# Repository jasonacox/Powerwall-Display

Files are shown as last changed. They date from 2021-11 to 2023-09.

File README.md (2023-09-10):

# Powerwall-Display
Tesla Powerwall display based on 7-segment TM1637 displays and ESP8266 to show current solar generation, powerwall (power and percentage), grid and load power usage. 

Powerwall-Display-Video (https://www.youtube.com/watch?v=8YzZw6ldIqQ "Play Video")

* Display1 (4-digit white/yellow): Solar Power Generated
* Display2 (6-digit red): Rotates thought the following Power metrics:
    * (H)ouse Load
    * (E)lectric Grid + direction animation
    * (P)owerwall Battery + direction animation
* Display3 (4-digit green): Powerwall Battery (% Full) + animation for charge/discharge

The display will show values in watts (W) for 1-9999W values and kilowatts (kW) for 10.0kW and above.
     
## 3D Printed Model
The 3D printed case houses the ESP8266 WeMos controller, two 4-digit displays and one 6-digit display.  The model has a cutout TESLA logo that can be backlit.

* Thingiverse - [Link](https://www.thingiverse.com/thing:5113169)
* Local STL - [Link](TeslaSolarDisplay.stl)
* Tinkercad Original - [Link](https://www.tinkercad.com/things/3FTXlFyVO4z-tesla-solar-display)

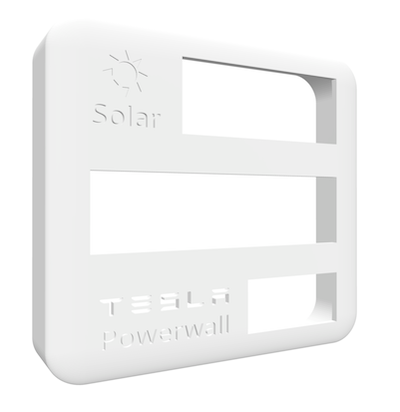
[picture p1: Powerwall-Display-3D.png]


## Electronics
The following components were used to build this kit:
* ESP8266 WeMos D1 Mini Controller - [Amazon](https://www.amazon.com/dp/B081PX9YFV/ref=cm_sw_em_r_mt_dp_48GWNB0ZD5XM511K98T9) | [AliExpress](https://www.aliexpress.com/item/1005001636509632.html?spm=a2g0s.9042311.0.0.21a34c4dPgfOzp)
* TM1637 0.56" 4-Digit LED Segment Display (White/Yellow) - [Amazon](https://www.amazon.com/dp/B07MCGDST2/ref=cm_sw_em_r_mt_dp_YD20SFT79CEE5465E9R0?_encoding=UTF8&psc=1) 
* TM1637 0.36" 4-Digit LED Segment Display (Green) - [Amazon](https://www.amazon.com/dp/B01DKISMXK/ref=cm_sw_em_r_mt_dp_17NDHA13Q8GRYH0W5KTG?_encoding=UTF8&psc=1)
* TM1637 0.56" 6-Digit LED Segment Display (Red) - [Amazon](https://www.amazon.com/dp/B08G1RYYTQ/ref=cm_sw_em_r_mt_dp_FHDSB6FT03TFHVS02QKB) | [AliExpress](https://www.aliexpress.com/item/1005002060120661.html?spm=a2g0s.9042311.0.0.21a34c4dPgfOzp)
* Optional - Green LEDs for Logo Backlight

## Powerwall Proxy
The display uses the [pyPowerwall proxy](https://github.com/jasonacox/pypowerwall/tree/main/proxy#pypowerwall-proxy-server) to connect with the Powerwall API. You you will need to install this on a local system (Raspberry Pi, Linux or Windows system) that is always running so that the display can pull the latest data. The proxy can be installed as a docker container.  Be sure to update the password, email, Powerwall host IP address and Timezone.

Proxy Install Instructions using Docker:

```bash
docker run \
    -d \
    -p 8675:8675 \
    -e PW_PASSWORD='your-powerwall-password' \
    -e PW_EMAIL='your-powerwall-email' \
    -e PW_HOST='your-powerwall-ip-address' \
    -e PW_TIMEZONE='America/Los_Angeles' \
    -e PW_CACHE_EXPIRE='20' \
    --name pypowerwall \
    --restart unless-stopped \
    jasonacox/pypowerwall
```

## Arduino Code
The code uses the [TM1637TinyDisplay](https://github.com/jasonacox/TM1637TinyDisplay) Arduino library to drive the 7-segment 4-digit and 6-digit displays (see installation [instructions here](https://github.com/jasonacox/TM1637TinyDisplay#installation)).

1. Use the Arudino sketch located [here](Powerwall-Display/Powerwall-Display.ino).

2. Update the Configuration Section for your Setup in the sketch:

```c++
// Configuration Settings           
#define FILTER 50               // Zero out power values less than this
#define PROXYHOST "10.0.x.x"    // Address of Proxy Server
#define PROXYPORT 8675          // Port of Proxy Server (default=8675)

// Wifi Configuration 
const char* WIFI_SSID = "WIFI_SSID";
const char* WIFI_PWD  = "WIFI_PASSWORD";

// Display GPIO Pins (Clock and Data)
#define CLK1 5    // Display 1 - 4-digit for SOLAR power display (Yellow)
#define DIO1 4
#define CLK2 14   // Display 2 - 6-digit for POWER display for Grid, Home and Powerwall (Red)
#define DIO2 12
#define CLK3 13   // Display 3 - 4-digit for BATTERY percentage (Green)
#define DIO3 16
#define TESLA 0   // Optional Tesla Logo LED
```

## Schematic

The cirucit is fairly simple. As noted above in the code, the ESP8266 module will need to drive the CLK (clock) and DIO (data) input on three different display modules, one 6-digit modules and two 4-digit modules. There is an optional output for the Logo LED.

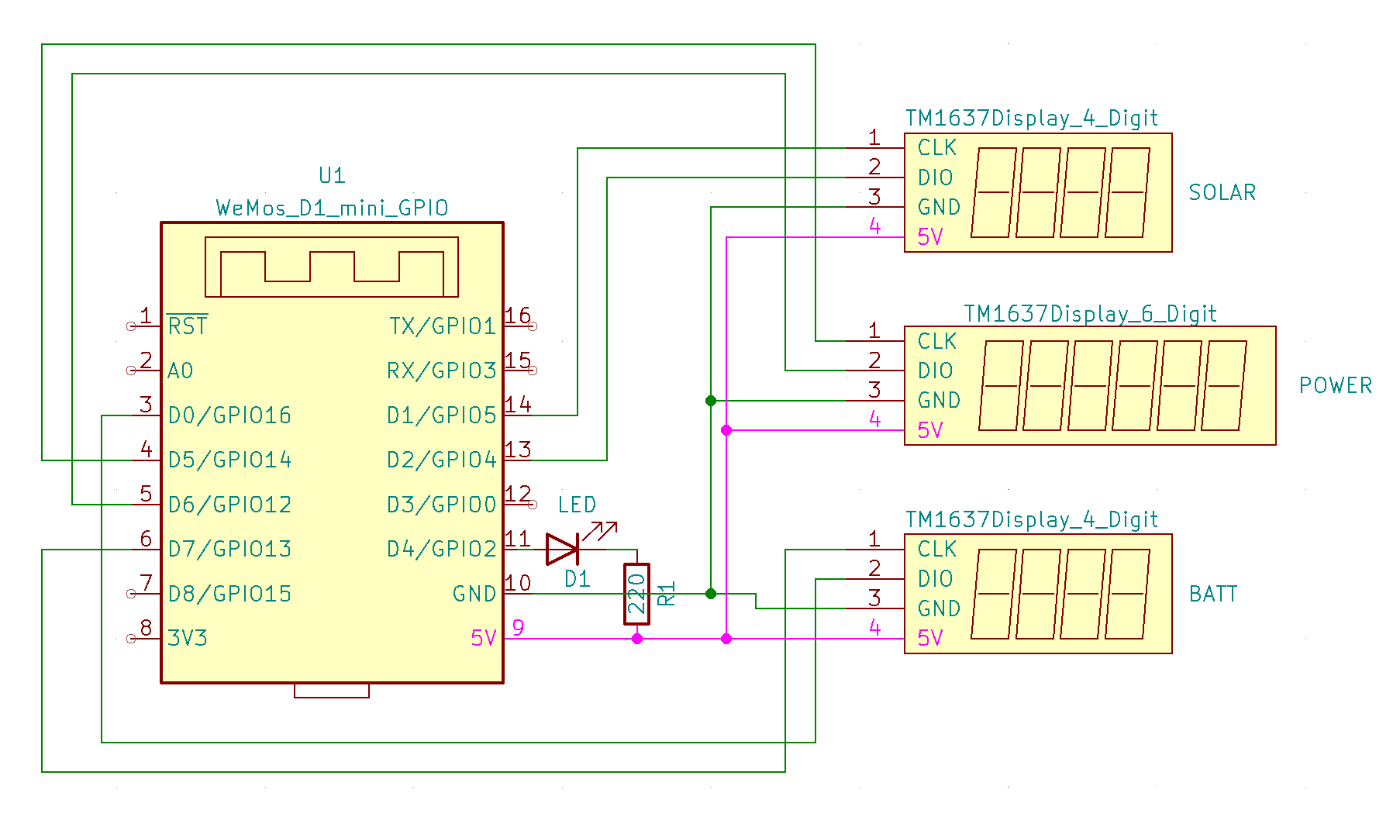
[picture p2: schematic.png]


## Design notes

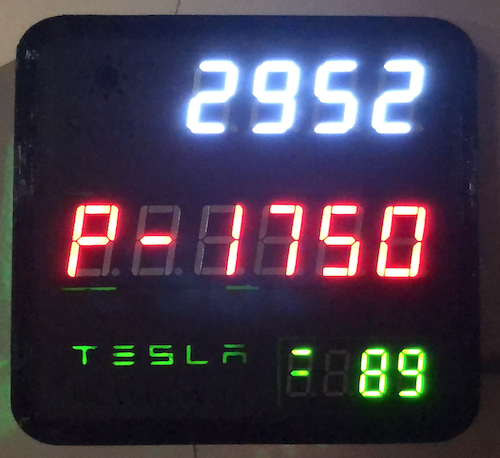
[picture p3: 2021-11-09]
Powerwall-Display.png

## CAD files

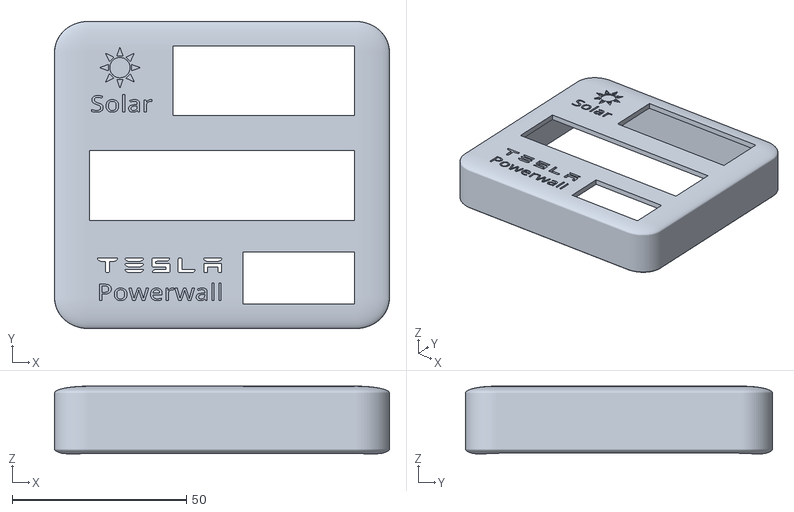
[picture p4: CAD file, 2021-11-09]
TeslaSolarDisplay.stl
96.0 x 88.0 x 19.4

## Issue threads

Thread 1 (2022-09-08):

ESP8266 to Powerwall

LucioB81, 2022-09-08:
Forst of all nice job, your work was very helpful!
One thing I can't seem to wrap my head around. Would it be possible to bypass the pypowerwall module and make the esp talk with the powerwall directly? I am obviously missing something but I cannot find what it is.

Thanks!
Lucio

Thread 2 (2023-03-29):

Issues communicating with the ESP8266

aparticka, 2023-03-29:
I find myself continually looking at the Tesla app to optimize usage (waiting to do laundry until the battery is nearing 100%, etc.). I figured something like this project would be possible and was happily surprised to find it, so thanks for all of the work that you've already done. I have the pypowerwall project running on a Raspberry Pi that I was using as a pihole already and that all works great, I can hit the /csv endpoint from my network and see the raw values. I ordered some of the parts you used - the ESP8266 modules and the 5-pack of different colored TM1637 displays. I have some Arduino experience, just playing around with a Mega 2560, but this particular ESP8266 is giving me issues (~90% of the time can't upload anything to it because it somehow can't connect to it). I was wondering if you also ran into any similar issues, and if so, how you fixed them. Thanks for reading if you made it this far, and thanks again for the well-documented project.

jasonacox, 2023-03-30:
Hi @aparticka - thanks for the kind words and encouragement!

Yes, I had issues with programming the ESP8266 from my MacBook and the Arduino IDE.  I needed to install the SiLabs [serial driver for the chip](https://www.silabs.com/products/development-tools/software/usb-to-uart-bridge-vcp-drivers) ([direct link](https://www.silabs.com/Support%20Documents/Software/Mac_OSX_VCP_Driver.zip)) - see https://github.com/nodemcu/nodemcu-devkit/wiki/Getting-Started-on-OSX .  You also need to install the Arduino board manager for ESP8266: http://arduino.esp8266.com/stable/package_esp8266com_index.json - this is done in the Arduino preferences settings:

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

Let me know if any of this helps. :)

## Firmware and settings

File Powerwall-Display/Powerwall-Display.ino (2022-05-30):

/*
  Powerwall-Display
  ESP8266 with Three TM1637 7-Segment Displays - STATIC WIFI SETTINGS
  https://github.com/jasonacox/Powerwall-Display

  Tesla Powerwall display based on 7-segment displays and ESP8266 to show 
  current solar generation, powerwall (power and percentage), grid and 
  load power usage.
  
  Description
     Three displays are set up to display metrics from Powerwall:
       Display1 (4-digit): Solar Power Generated (W)
       Display2 (6-digit): Rotates display of the following Power metrics:
                             (H)ouse Load (W)
                             (E)lectric Grid (W) + direction animation
                             (P)owerwall Battery (W) + direction animation
       Display3 (4-digit): Powerwall Battery (% Full) + animation

     Displays in W unit for 1-9999W values and kW for 10.0kW and above.

  This sketch requires pyPowerwall proxy - http://<proxy-address>:8675/csv

     Proxy Install Instructions:
          docker run \
              -d \
              -p 8675:8675 \
              -e PW_PASSWORD='your-powerwall-password' \
              -e PW_EMAIL='your-powerwall-email' \
              -e PW_HOST='your-powerwall-ip-address' \
              -e PW_TIMEZONE='America/Los_Angeles' \
              -e PW_DEBUG='yes' \
              -e PW_CACHE_EXPIRE='20' \
              --name pypowerwall \
              --restart unless-stopped \
              jasonacox/pypowerwall

  Author: Jason A. Cox - @jasonacox
  Date: 1 November 2021
*/

#define VERSION 1.00
#define SENSORID 101 

// Configuration Settings           
#define FILTER 50               // Zero out power values less than this
#define PROXYHOST "10.0.x.x"    // Address of Proxy Server
#define PROXYPORT 8675          // Port of Proxy Server (default=8675)

// Wifi Configuration 
const char* WIFI_SSID = "WIFI_SSID";
const char* WIFI_PWD  = "WIFI_PASSWORD";

// Display GPIO Pins (Clock and Data)
#define CLK1 5    // Display 1 - 4-digit
#define DIO1 4
#define CLK2 14   // Display 2 - 6-digit
#define DIO2 12
#define CLK3 13   // Display 3 - 4-digit
#define DIO3 16
#define TESLA 0   // Optional Tesla Logo LED
#define LED 2

// Includes
#include <Arduino.h>
#include <ESP8266WiFi.h>
#include <ESP8266WiFiMulti.h>
#include <ESP8266HTTPClient.h>
#include <WiFiClient.h>
#include <TM1637TinyDisplay.h>
#include <TM1637TinyDisplay6.h>

// INITIALIZE TM1637TinyDisplay
TM1637TinyDisplay display1(CLK1, DIO1);   // Solar
TM1637TinyDisplay display2(CLK2, DIO2);   // Battery Level
TM1637TinyDisplay6 display3(CLK3, DIO3);  // Power for Grid, House, Bat

// WIFI
ESP8266WiFiMulti WiFiMulti;
WiFiClient client;
HTTPClient http;

// Globals
const uint8_t ANIMATION[36][4] PROGMEM = {
  /* Animation Data - HGFEDCBA Map */
  { 0x00, 0x00, 0x00, 0x00 },  // Frame 0
  { 0x01, 0x00, 0x00, 0x00 },  // Frame 1
  { 0x40, 0x01, 0x00, 0x00 },  // Frame 2
  { 0x08, 0x40, 0x00, 0x01 },  // Frame 3
  { 0x00, 0x08, 0x01, 0x40 },  // Frame 4
  { 0x01, 0x00, 0x40, 0x08 },  // Frame 5
  { 0x40, 0x01, 0x08, 0x00 },  // Frame 6
  { 0x08, 0x40, 0x00, 0x01 },  // Frame 7
  { 0x00, 0x08, 0x01, 0x40 },  // Frame 8
  { 0x01, 0x01, 0x40, 0x08 },  // Frame 9
  { 0x40, 0x40, 0x09, 0x00 },  // Frame 10
  { 0x08, 0x08, 0x40, 0x01 },  // Frame 11
  { 0x01, 0x00, 0x08, 0x40 },  // Frame 12
  { 0x40, 0x01, 0x00, 0x08 },  // Frame 13
  { 0x08, 0x40, 0x01, 0x00 },  // Frame 14
  { 0x01, 0x09, 0x41, 0x01 },  // Frame 15
  { 0x40, 0x40, 0x48, 0x40 },  // Frame 16
  { 0x08, 0x08, 0x08, 0x08 },  // Frame 17
  { 0x00, 0x00, 0x00, 0x00 },  // Frame 18
  { 0x00, 0x08, 0x00, 0x00 },  // Frame 19
  { 0x00, 0x00, 0x08, 0x00 },  // Frame 20
  { 0x00, 0x00, 0x00, 0x08 },  // Frame 21
  { 0x00, 0x00, 0x00, 0x04 },  // Frame 22
  { 0x00, 0x00, 0x00, 0x02 },  // Frame 23
  { 0x00, 0x00, 0x00, 0x01 },  // Frame 24
  { 0x00, 0x00, 0x01, 0x00 },  // Frame 25
  { 0x00, 0x01, 0x00, 0x00 },  // Frame 26
  { 0x01, 0x00, 0x00, 0x00 },  // Frame 27
  { 0x20, 0x00, 0x00, 0x00 },  // Frame 28
  { 0x10, 0x00, 0x00, 0x00 },  // Frame 29
  { 0x08, 0x00, 0x00, 0x00 },  // Frame 30
  { 0x00, 0x08, 0x00, 0x00 },  // Frame 31
  { 0x00, 0x00, 0x08, 0x00 },  // Frame 32
  { 0x00, 0x00, 0x00, 0x08 },  // Frame 33
  { 0x00, 0x00, 0x00, 0x80 },  // Frame 34
  { 0x00, 0x00, 0x00, 0x3f }   // Frame 35
};
char line[1500];
char host[20];
char ver[20];
float grid, house, solar, battery, batterylevel;
char dgrid[100], dhouse[100], dsolar[100], dbattery[100], dbatterylevel[100];
unsigned long previousMillis = 0;         // prior counter
const long interval = 5000;               // interval counter in milliseconds
const int fetch = 20 / (interval / 1000); // update data from server in seconds
unsigned long previousSecond = 0;
int counter = 1;
int count = fetch;
int state = 0;
int dispstate = 0;
time_t today;
int animation = 0;     // frame counter for animation (1 per sec)
unsigned char sym[6];
char url[100];

// ------------------------------------ SETUP ------------------------------------
// ------------------------------------ SETUP ------------------------------------
// ------------------------------------ SETUP ------------------------------------

void setup() {
  time_t timevar;

  pinMode(LED, OUTPUT);   // LED for ESP
  digitalWrite(LED, 1);   // Turn Off
  pinMode(TESLA, OUTPUT); // LED for TESLA Logo
  digitalWrite(TESLA, 1); // Turn Off

  display1.setBrightness(2);
  display2.setBrightness(BRIGHT_HIGH);
  display3.setBrightness(BRIGHT_HIGH);

  display1.clear();
  display3.showString("TESLA");
  display2.showString("boot");

  sprintf(host, "Solar-%d", SENSORID);
  sprintf(ver, "v%0.2f", VERSION);
  sprintf(url, "http://%s:%d/csv", PROXYHOST, PROXYPORT);

  display1.showString(host);
  display2.showString(ver);
  display3.showString("TESLA");
  display2.showString("boot");
  delay(100);
  display1.showAnimation_P(ANIMATION, FRAMES(ANIMATION), TIME_MS(10));

  // Start up Serial
  Serial.begin(115200);
  delay(1000);
  while (!Serial);   // time to get serial running
  Serial.println();
  Serial.printf("SolarStation %s [%s]\n", host, ver);
  Serial.println("Starting up WiFi...");

  // Initialize the WiFi system
  digitalWrite(LED, 0); // Turn ON
  WiFi.mode(WIFI_STA);              // remove Fairylink default AP
  WiFi.begin(WIFI_SSID, WIFI_PWD);

  int counter = 0;
  WiFi.hostname(host);
  display3.showString("SCAN..");
  while (WiFi.status() != WL_CONNECTED) {
    delay(200);
    Serial.print(".");
    // display1.showNumber(counter);
    if ((counter % 4) == 0) display1.showString("-   ");
    if ((counter % 4) == 1) display1.showString(" -  ");
    if ((counter % 4) == 2) display1.showString("  - ");
    if ((counter % 4) == 3) display1.showString("   -");
    display2.showNumber(counter);
    counter++;
    if (counter > 600) {
      // reboot
      ESP.restart();
    }
  }
  digitalWrite(LED, 1); // Turn Off
  digitalWrite(TESLA, 0); // Turn On
  display3.showString("ONLINE");
  // Finish Animation
  while ((counter % 4) != 0) {
    delay(200);
    if ((counter % 4) == 0) display1.showString("-   ");
    if ((counter % 4) == 1) display1.showString(" -  ");
    if ((counter % 4) == 2) display1.showString("  - ");
    if ((counter % 4) == 3) display1.showString("   -");
    counter++;
  }
  display1.clear();
  delay(1000);
  display3.clear();
  display2.clear();
}


// ------------------------------------ LOOP ------------------------------------
// ------------------------------------ LOOP ------------------------------------
// ------------------------------------ LOOP ------------------------------------

void loop() {

  unsigned long currentMillis = millis();

  // ANIMATION for Power Direction - Run every 250ms
  if (currentMillis - previousSecond >= 250) {
    previousSecond = currentMillis;
    animation++;
    if (animation > 4) {
      animation = 0;
    }
    // Animation for Battery
    sym[0] = animationSeg(battery);
    display2.setSegments(sym, 1, 0);

    // Animation for Grid
    if (state == 2) {
      sym[0] = animationSeg(grid);
      display3.setSegments(sym, 1, 1);
    }
    if (state == 0) {
      sym[0] = animationSeg(battery);
      display3.setSegments(sym, 1, 1);
    }

  }

  // DISPLAY Metrics based on State - Run every interval (ms)
  if ((currentMillis - previousMillis >= interval) || (currentMillis < previousMillis) ) {
    previousMillis = currentMillis;

    // FETCH Data from Powerwall Proxy
    if (count >= fetch) {
      count = 0;
      // wait for WiFi connection
      if ((WiFiMulti.run() == WL_CONNECTED)) {
        Serial.print("[HTTP] begin...\n");

        // pull solar data from server
        if (http.begin(client, url)) {  // HTTP
          Serial.printf("[HTTP] GET %s\n", url);

          // start connection and send HTTP header
          int httpCode = http.GET();
          if (httpCode > 0) {
            // Sent GET Request
            Serial.printf("[HTTP] GET... code: %d\n", httpCode);
            if (httpCode == HTTP_CODE_OK || httpCode == HTTP_CODE_MOVED_PERMANENTLY) {
              // Read response
              String payload = http.getString();
              payload.toCharArray(line, 1400);
              Serial.printf("Payload=%s\n", line);
              // Expected format: grid,house,solar,battery,batterylevel
              int result = sscanf(line, "%f,%f,%f,%f,%f",
                                  &grid, &house, &solar, &battery, &batterylevel);
              Serial.printf("results = %d [%f, %f, %f, %f, %f]\n",
                            result, grid, house, solar, battery, batterylevel);
              if (result < 5) {
                Serial.println("Data Error on GET\n");
              }
              else {
                // convert battery level range to match Tesla App
                batterylevel = ( (batterylevel / 0.95) - (5 / 0.95) );

                // filter out close to zero noise
                if (abs(grid) < FILTER) grid = 0;
                if (abs(solar) < FILTER) solar = 0;
                if (abs(battery) < FILTER) battery = 0;
                
                // Uncomment to force large number test
                // grid = -12456;
                // solar = 10123;
                // battery = 24012;
                // house = 15777;
                
                // create formatted strings
                sprintf(dgrid, "E%5.0f", (float(abs(grid))));
                sprintf(dhouse, "H%5.0f", (house));
                sprintf(dsolar, "%0.1f", (solar / 1000.0));
                sprintf(dbattery, "P%5.0f", (float(abs(battery))));
                sprintf(dbatterylevel, "%0.0f", batterylevel);

                Serial.printf("Strings = %s, %s, %s, %s, %s\n",
                              dgrid, dhouse, dsolar, dbattery, dbatterylevel);
              }
            }
            else {
              Serial.printf("[HTTP] Server Error %d\n", httpCode);
            }
          } else {
            Serial.printf("[HTTP] GET... failed, error: %s\n", http.errorToString(httpCode).c_str());
          }
          http.end();
        } else {
          Serial.printf("[HTTP] Unable to connect\n");
        }
      } // if ((WiFiMulti.run() == WL_CONNECTED))
      else
      {
        // Unable to connect to WiFi - Retry
        digitalWrite(TESLA, 1); // Turn Off
        digitalWrite(LED, 0); // Turn On
        counter = 0;
        display3.showString("SCAN.."); // SEArCH
        while (WiFi.status() != WL_CONNECTED) {
          delay(500);
          Serial.print(".");
          if ((counter % 4) == 0) display1.showString("-   ");
          if ((counter % 4) == 1) display1.showString(" -  ");
          if ((counter % 4) == 2) display1.showString("  - ");
          if ((counter % 4) == 3) display1.showString("   -");
          display2.showNumber(counter);
          counter++;
          if (counter > 600) {
            // reboot
            ESP.restart();
          }
        }
        display3.showString("ONLINE");
        display1.clear();
        display2.clear();
        digitalWrite(LED, 1); // Turn Off
        digitalWrite(TESLA, 0); // Turn On
        delay(500);
      } // else
    } // if (count >= fetch)

    // Refresh displays

    // Solar Production
    if (solar > 9999) display1.showNumber(float(solar / 1000), 2);
    else display1.showNumber(int(solar));

    // Battery Levels
    // display2.showLevel(int(batterylevel), false);
    display2.showNumber(int(batterylevel));

    // House, Grid and Battery
    // To add a dot after Letter: display.showString("______",6,0,0b10000000);
    switch (state) {
      case 0:
        // House (H)
        display3.setBrightness(6);
        if (house > 9999) {
          display3.showString("H     ");
          display3.showNumber(float(house / 1000), 1, 4, 2);
        }
        else {
          display3.showString(dhouse, 6, 0);
        }
        state++;
        break;
      case 1:
        // Grid (E)
        display3.setBrightness(4);
        if ((abs(grid)) > 9999) {
          display3.showString("E     ");
          display3.showNumber(float((abs(grid)) / 1000), 1, 4, 2);
        }
        else {
          display3.showString(dgrid, 6, 0);
        }
        state++;
        break;
      case 2:
      default:
        // Battery (P)
        display3.setBrightness(2);
        if ((abs(battery)) > 9999) {
          display3.showString("P     ");
          display3.showNumber(float((abs(battery)) / 1000), 1, 4, 2);
        }
        else {
          display3.showString(dbattery, 6, 0);
        }
        state = 0;
        break;
    }
    count++;
  }
}

// Function Helper - Return animation frame char
char animationSeg(int value) {
  int frame;
  frame = animation;
  if (value == 0) return (0b00000000); // no flow
  if (value > 0) {
    frame = 4 - animation;
  }
  switch (frame) {
    case 0:
      return (0b00000000);
    case 1:
      return (0b00001000);
    case 2:
      return (0b01000000);
    case 3:
      return (0b00000001);
    case 4:
    default:
      return (0b00000000);
  }
}

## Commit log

2022-01-23 Add schematic
    [PW-Display.kicad_sch]
2022-01-23 Updated schematic
2022-01-23 Updated kicad
    [PW-Display.kicad_sch]
